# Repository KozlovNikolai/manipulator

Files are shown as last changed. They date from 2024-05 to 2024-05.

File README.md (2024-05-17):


<!-- PROJECT LOGO -->
<br />
<div align="center">
  <a href="https://github.com/github_username/repo_name">
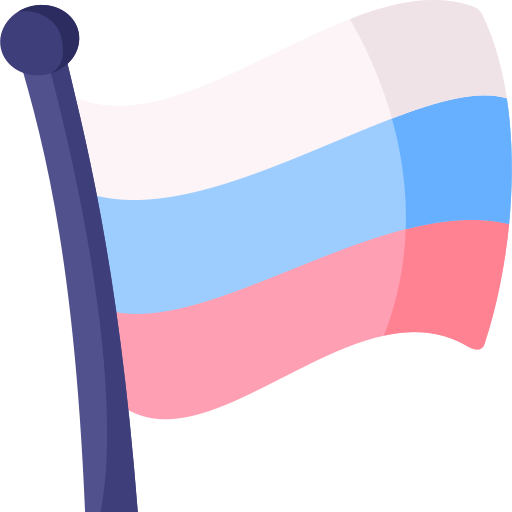
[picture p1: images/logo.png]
    
  </a>

<h3 align="center">Проект автоматического телеграфного ключа для тренировки и соревнований по скоростному телеграфированию</h3>

<!-- TABLE OF CONTENTS -->
<details>
  <summary>Содержание</summary>
  <ol>
    <li><a href="#о-проекте">О проекте</a></li>
    <li><a href="#начало">Начало</a></li>
    <li><a href="#лицензия">Лицензия</a></li>
    <li><a href="#контакты">Контакты</a></li>
  </ol>
</details>

<!-- ABOUT THE PROJECT -->
## О проекте

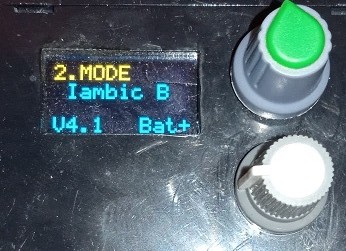
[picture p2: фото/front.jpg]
Product Name Screen Shot


<p align="left">
Проект был задуман как ответ на запрос от телеграфистов скоростников на изготовление автоматического ключа, отвещающего следующим требованиям:</p>

* <p align="left">скорость работы ключа не менее 400 СРМ</p>
* <p align="left">поддержка всех режимов работы манипулятора: Iambic A, Iambic AT, Iambic B, Classic</p>
* <p align="left">два выхода управления: реле и оптопара</p>
* <p align="left">звуковая индикация</p>
* <p align="left">индикация заряда батареи</p>
* <p align="left">режим тренировки/контест</p>
* <p align="left">вывод в текстовый редактор на компьютер набираемых символов (как будто их набирают на клавиатуре)</p>
* <p align="left">отображение всех настроек и режимов на дисплее</p>
* <p align="left">сохранение текущих настроек в энергонезависимую память</p>

Текущая версия = 4.32

<p align="right">(<a href="#readme-top">back to top</a>)</p>

<!-- GETTING STARTED -->
## Начало

Для установки программы требуются:

* Arduino IDE
* Микроконтроллер AtMega32u4

После прошивки требуется вставить контроллер в манипулятор, изготовленный в соответствии с <a href="https://github.com/KozlovNikolai/manipulator/tree/master/manipulyator">проектом</a>.

<p align="right">(<a href="#readme-top">back to top</a>)</p>

<!-- LICENSE -->
## Лицензия

Распостраняется свободно.

<p align="right">(<a href="#readme-top">back to top</a>)</p>

<!-- CONTACT -->
## Контакты

Николай Козлов:\
Telegram: @gremiha3\
e-mail: gremiha3@yandex.ru

Project Link: [https://github.com/KozlovNikolai/manipulator](https://github.com/KozlovNikolai/manipulator)

<p align="right">(<a href="#readme-top">back to top</a>)</p>

<!-- MARKDOWN LINKS & IMAGES -->
<!-- https://www.markdownguide.org/basic-syntax/#reference-style-links -->
[arduino-img]: https://cdn.arduino.cc/header-footer/prod/assets/headerLogo-arduino.svg
[arduino-link]: https://www.arduino.cc/
[front-img]: фото/front.jpg

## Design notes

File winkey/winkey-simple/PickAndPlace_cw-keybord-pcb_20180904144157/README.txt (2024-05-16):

为了支持多语言，立创EDA的BOM和坐标文件(CSV文件)均采用UNICODE编码，以制表符为CSV分隔符，如果你上传BOM至元件商城(如立创商城)无法使用，或者发送坐标文件至PCB制造商(如深圳嘉立创)无法使用，请自行转换CSV文件编码与分隔符。

推荐的转换方式：使用Excel或WPS另存为新的CSV文件。以Excel为例，用Excel打开CSV文件后，依次点击或选择：另存为——其它格式——CSV(逗号分隔)(*.csv)。

也可以使用任何文本编辑器(如Windows记事本)打开该CSV文件，另存为ANSI或UTF-8编码格式。如有必要，还需替换所有制表符为英文逗号。

In order to support multiple languages, BOM and coordinate files (CSV file) are UNICODE encoded and tab-based. If the CSV file cannot be read by your components vendor or PCB manufacturer, please convert the encoding and change the delimiter.

Recommended solution: Save as a new CSV file in Excel or WPS. For example, open a CSV file in Excel, click or select: Save As - Other Formats - CSV (Comma Separated) (*. csv).

You can also open the CSV file with any text editor (such as Windows Notepad) and save as ANSI or UTF-8 encoding. If necessary, replace all tabs with commas.

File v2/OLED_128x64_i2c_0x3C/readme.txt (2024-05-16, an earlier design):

Радиодетали недорого почтой из Москвы и в Москве круглосуточно 24/7, есть доставка - www.mkPochtoi.ru

миниатюрный дисплей около 24 мм диагональ 128х64 точки интерфес i2c 

1) в Arduino IDE открыть - скеч - Подкл библ - Добавить ZIP-библ
 и добавить  Adafruit_GFX.zip  а затем Adafruit_SSD1306.zip
 
2) подключите дисплей к Arduino через преобразователь уровей на 3.3 вольта (например через модуль согласования логических уровней)
 
3) в Arduino IDE открыть - Файл - открыть -  откройте скеч
C:\Users\......\Documents\Arduino\libraries\Adafruit_SSD1306\examples\ssd1306_128x64_i2c/ssd1306_128x64_i2c.ino

4) нажать кнопку "загрузить" - после компиляции и загрузки на дисплее должна появится демка

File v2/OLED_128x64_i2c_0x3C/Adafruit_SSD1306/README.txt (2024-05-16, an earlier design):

Радиодетали недорого почтой из Москвы и в Москве круглосуточно 24/7, есть доставка - www.mkPochtoi.ru

This is a library for our Monochrome OLEDs based on SSD1306 drivers

  Pick one up today in the adafruit shop!
  ------> http://www.adafruit.com/category/63_98

  i2c or
These displays use SPI to communicate, 4 or 5 pins are required to  
interface

Adafruit invests time and resources providing this open source code, 
please support Adafruit and open-source hardware by purchasing 
products from Adafruit!

Written by Limor Fried/Ladyada  for Adafruit Industries.  
Scrolling code contributed by Michael Gregg
BSD license, check license.txt for more information
All text above must be included in any redistribution

To download. click the DOWNLOADS button in the top right corner, rename the uncompressed folder Adafruit_SSD1306. Check that the Adafruit_SSD1306 folder contains Adafruit_SSD1306.cpp and Adafruit_SSD1306.h

Place the Adafruit_SSD1306 library folder your <arduinosketchfolder>/libraries/ folder. You may need to create the libraries subfolder if its your first library. Restart the IDE.

You will also have to download the Adafruit GFX Graphics core which does all the circles, text, rectangles, etc. You can get it from
https://github.com/adafruit/Adafruit-GFX-Library
and download/install that library as well

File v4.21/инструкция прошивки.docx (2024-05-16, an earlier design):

История изменений в самом конце!

1 Скачиваем «arduino ide» https://downloads.arduino.cc/arduino-1.8.13-windows.exe или зайти на сайт https://www.arduino.cc/en/software и выбрать нужную версию.
2 Устанавливаем, при установке оставляем все галки включая установку драйверов.

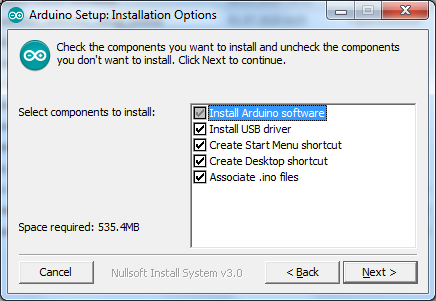
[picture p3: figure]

3 При установке доверяем программе во всех случаях:

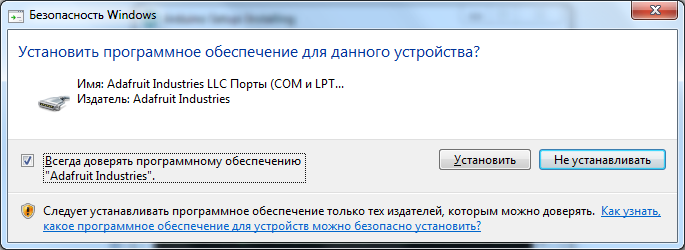
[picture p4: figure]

4 При появлении надписи «COMPLETED» нажимаем «CLOSE»

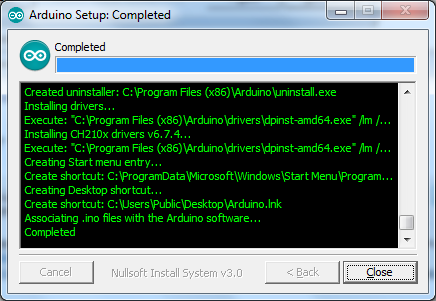
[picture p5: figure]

5 Запускаем Arduino IDE

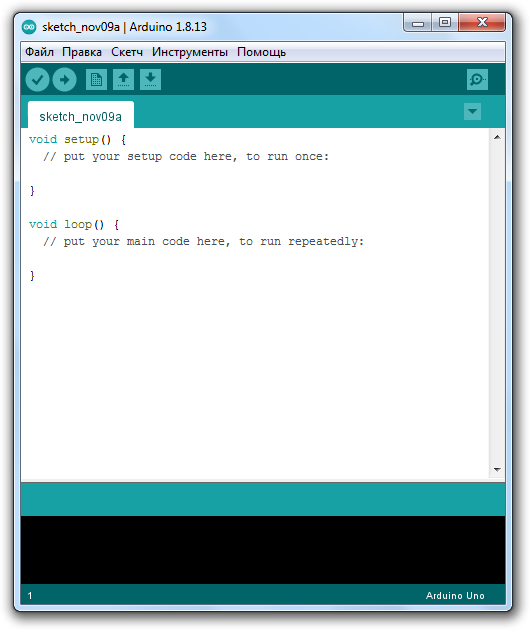
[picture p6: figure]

6 Открываем файл прошивки:

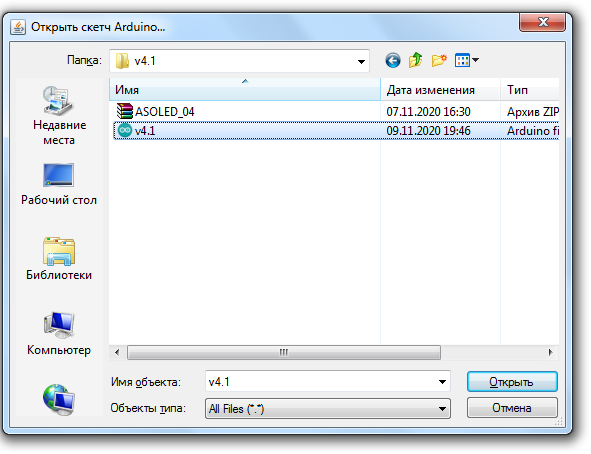
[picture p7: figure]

7 Выбираем нужный контроллер:

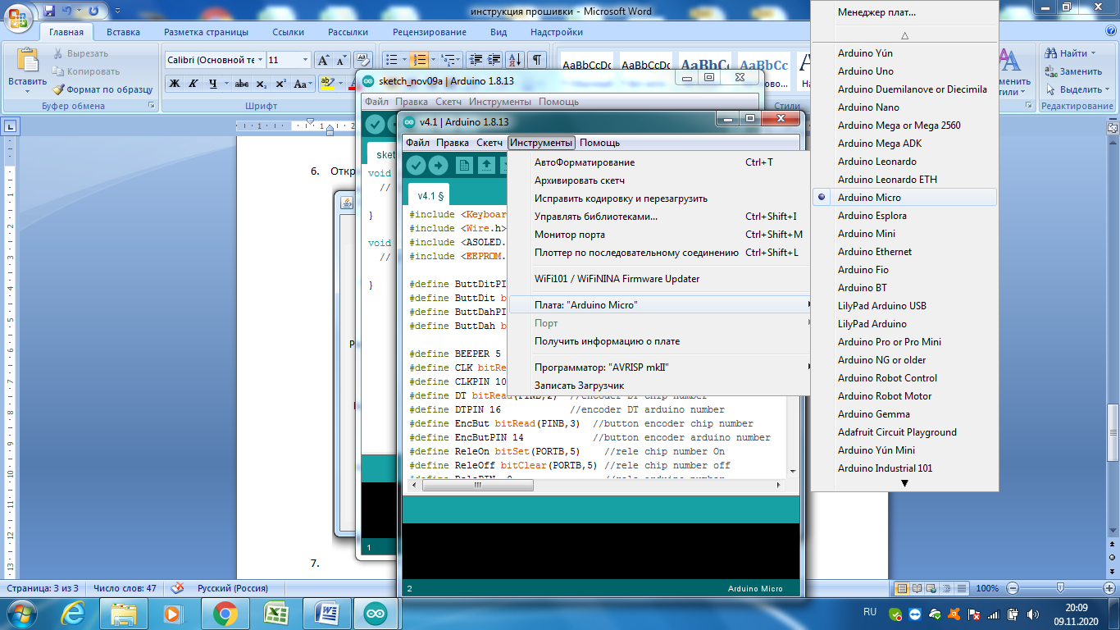
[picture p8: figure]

8 Подключаем контроллер в USB порт, если Arduino IDE установился правильно, то драйвер на контроллер установится автоматически:

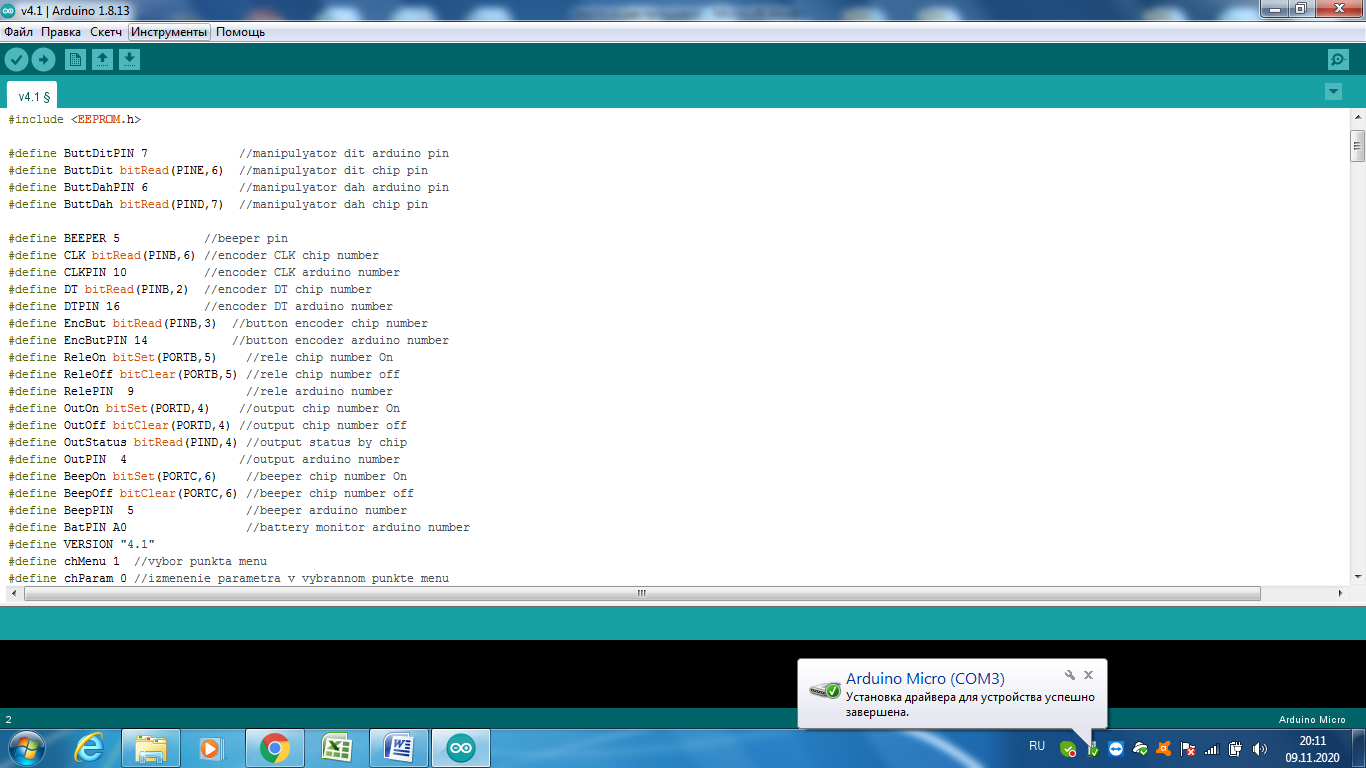
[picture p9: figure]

9 Выбираем порт:

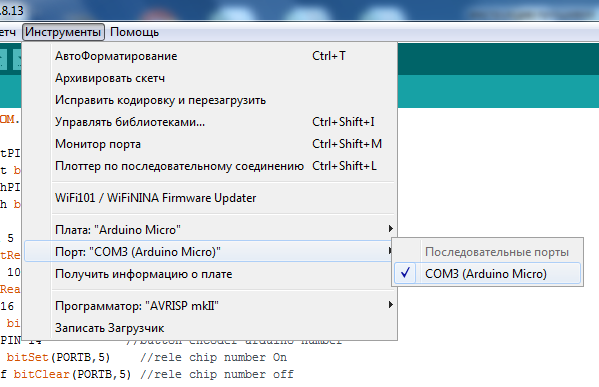
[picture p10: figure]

10 Добавляем недостающую библиотеку:

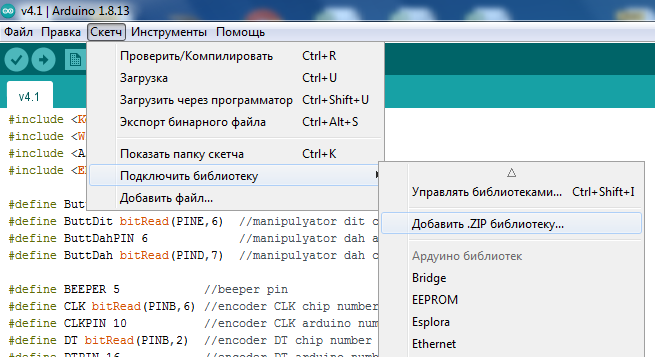
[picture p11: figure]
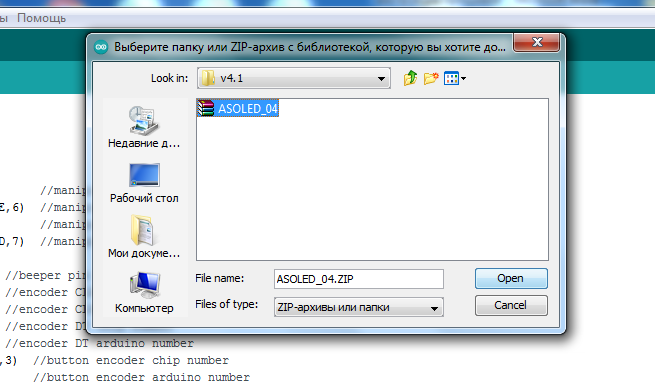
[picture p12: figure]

11 Нажимаем кнопку прошивки (указана стрелкой):

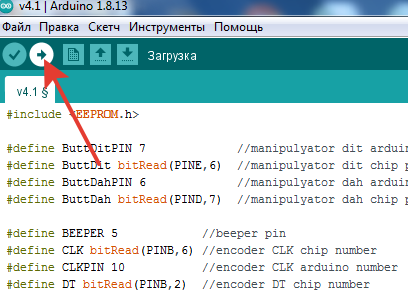
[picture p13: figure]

12 При прошивке может установиться дополнительный драйвер (обычно только при первой прошивке)

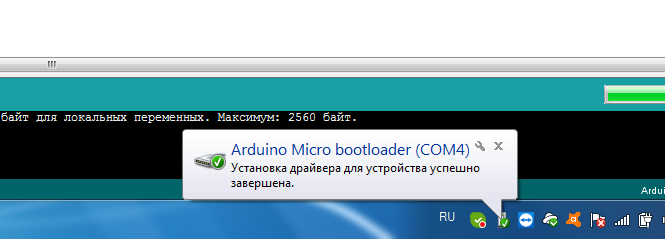
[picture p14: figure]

13 Если прошивка завершилась удачно, то появится надпись «Загрузка завершена»

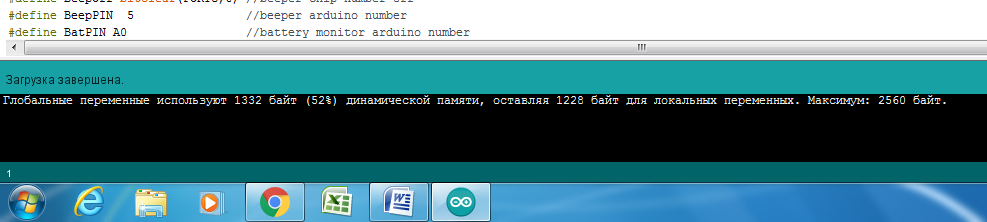
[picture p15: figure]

В нижнем правом углу есть индикатор батареи. Его значения:

- USB – питание от USB порта. При этом реле работать не будет (см. выше)
- Bat+ питание от батареи в норме.
- Bat- (мигает) напряжение упало до , примерно, 2.5 вольт.

Что бы функция батареи работала на устройствах с прошивкой V3.0, надо соединить контакт питания Реле с контактом А0 контроллера.

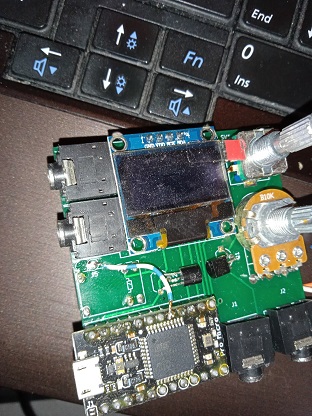
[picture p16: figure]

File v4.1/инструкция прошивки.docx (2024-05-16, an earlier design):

1 Скачиваем «arduino ide» https://downloads.arduino.cc/arduino-1.8.13-windows.exe или зайти на сайт https://www.arduino.cc/en/software и выбрать нужную версию.
2 Устанавливаем, при установке оставляем все галки включая установку драйверов.


3 При установке доверяем программе во всех случаях:


4 При появлении надписи «COMPLETED» нажимаем «CLOSE»


5 Запускаем Arduino IDE


6 Открываем файл прошивки:


7 Выбираем нужный контроллер:


8 Подключаем контроллер в USB порт, если Arduino IDE установился правильно, то драйвер на контроллер установится автоматически:


9 Выбираем порт:


10 Добавляем недостающую библиотеку:


11 Нажимаем кнопку прошивки (указана стрелкой):


12 При прошивке может установиться дополнительный драйвер (обычно только при первой прошивке)


13 Если прошивка завершилась удачно, то появится надпись «Загрузка завершена»


В прошивке 4.1 следующие функции:

1 Выбор скорости CPM, скорость WPM вычисляется как 1/5
2 Выбор режима работы (согласно диаграмм, приложенных ниже):
  2.a Ямбик А - чередование
  2.b Ямбик АТ – чередование + память на точку
  2.c Ямбик В – чередование + память на точку и тире
  2.d Классический – нет памяти и нет чередования
3 Функция клавиатуры. При включении питания всегда выключена.
4 Функция реле. Реле работает только при включенной батарее (питание по USB может быть тоже включено, но реле 3 вольтовое и его питание только от батареи. Можно заменить реле на 5 вольтовое, или через резистор запитать штатное реле, и запитать от 5 вольт после преобразователя – не пробовал, пока так)
5 Функция Автопаузы. Пока пустой пункт меню.
6 Длительность тире в размерности длительности точки.
7 Реверс что-бы поменять местами функции точки и тире на манипуляторе.
8 Долгое нажатие – сохраняет все настройки кроме Функции клавиатуры.

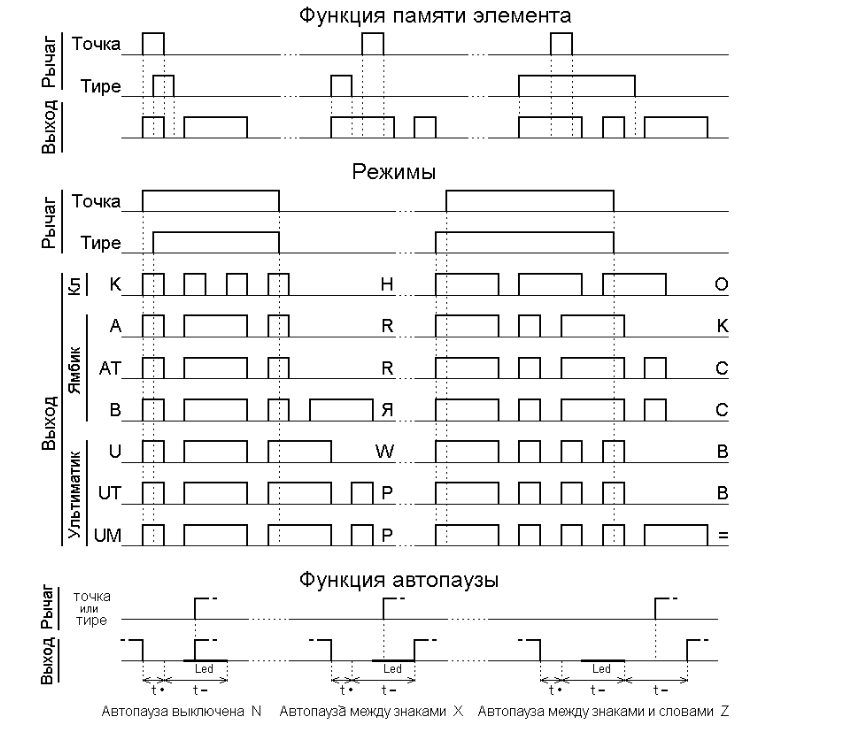
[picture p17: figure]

В нижнем правом углу есть индикатор батареи. Его значения:

- USB – питание от USB порта. При этом реле работать не будет (см. выше)
- Bat+ питание от батареи в норме.
- Bat- (мигает) напряжение упало до , примерно, 2.5 вольт.

Что бы функция батареи работала на устройствах с прошивкой V3.0, надо соединить контакт питания Реле с контактом А0 контроллера.


Остальные фото Меню:

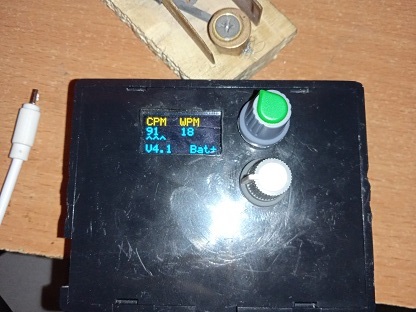
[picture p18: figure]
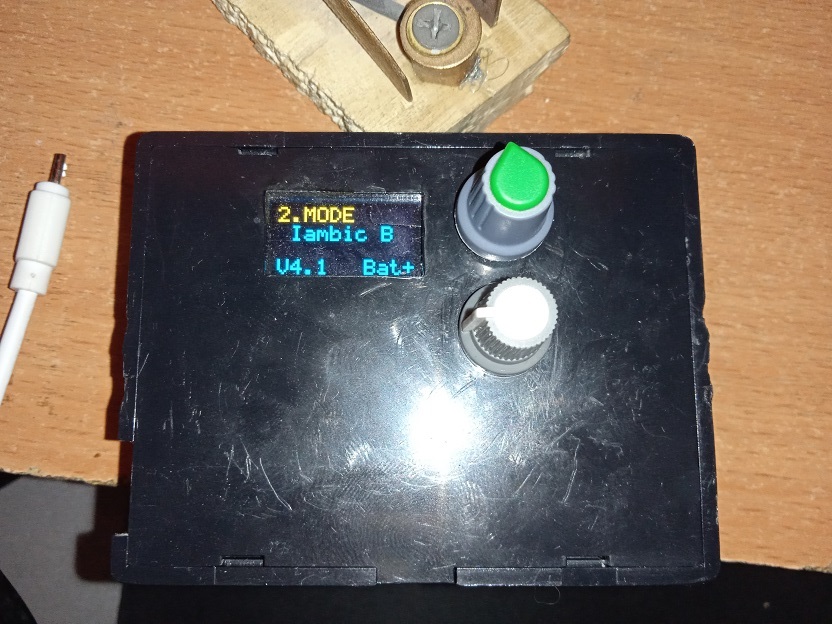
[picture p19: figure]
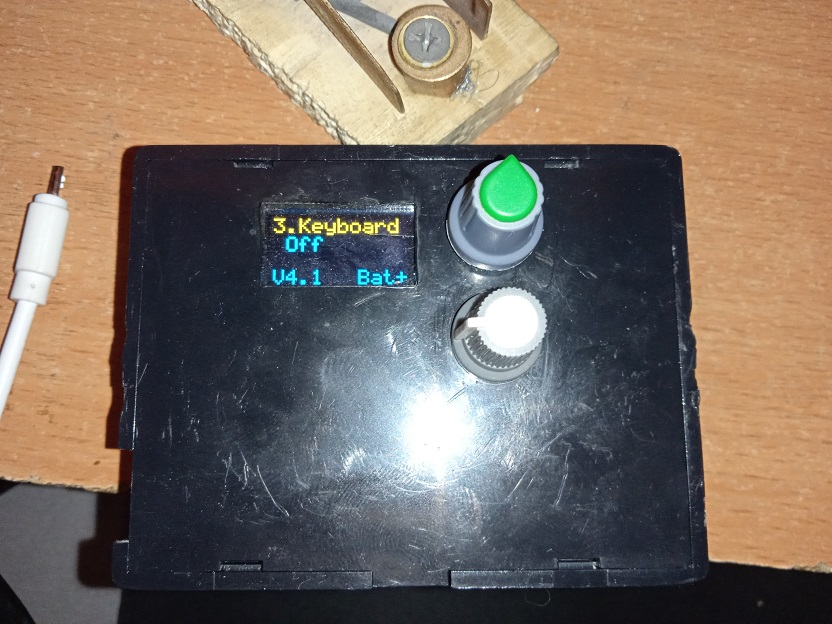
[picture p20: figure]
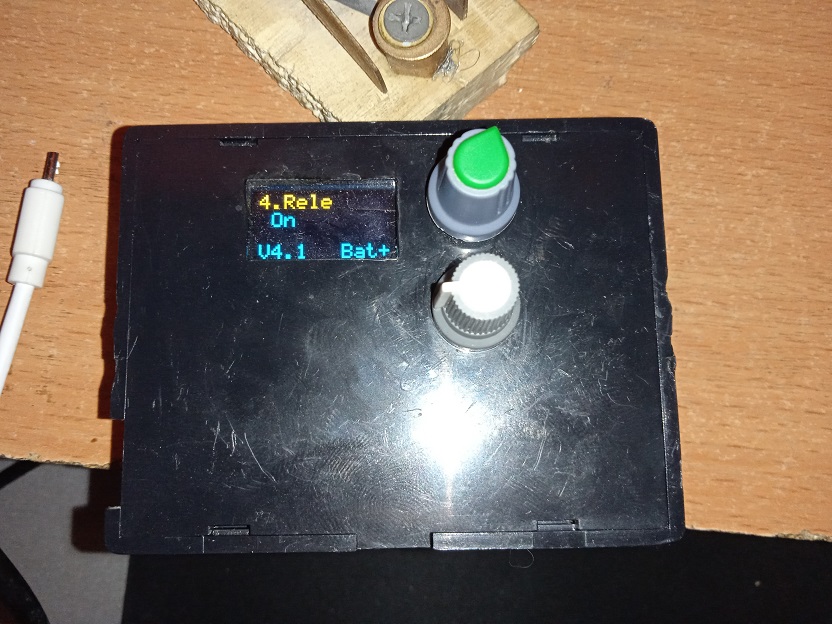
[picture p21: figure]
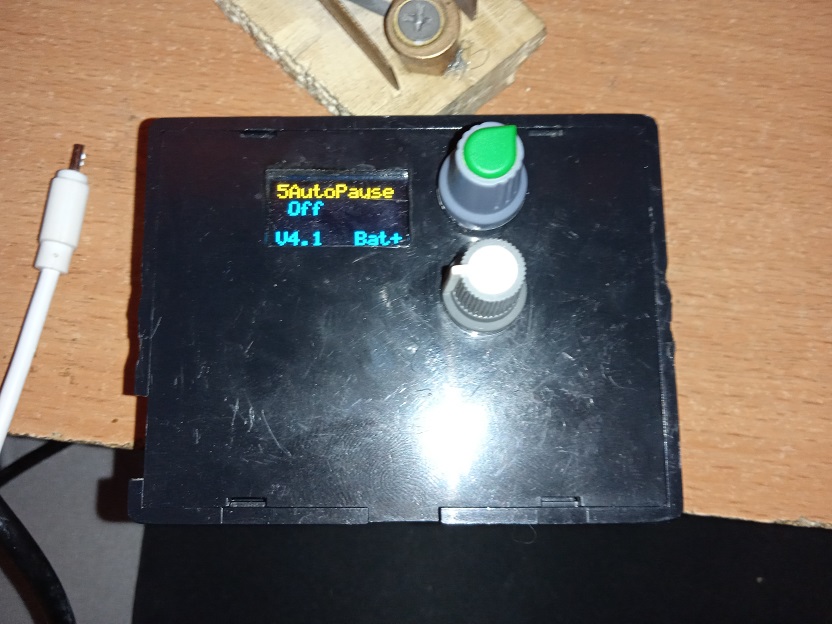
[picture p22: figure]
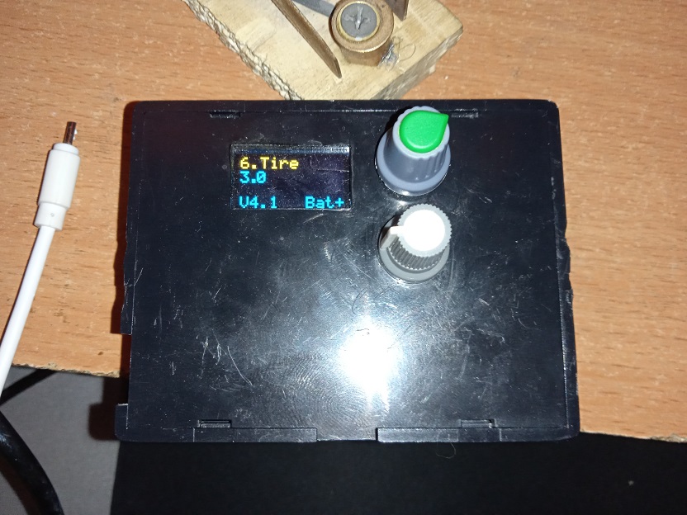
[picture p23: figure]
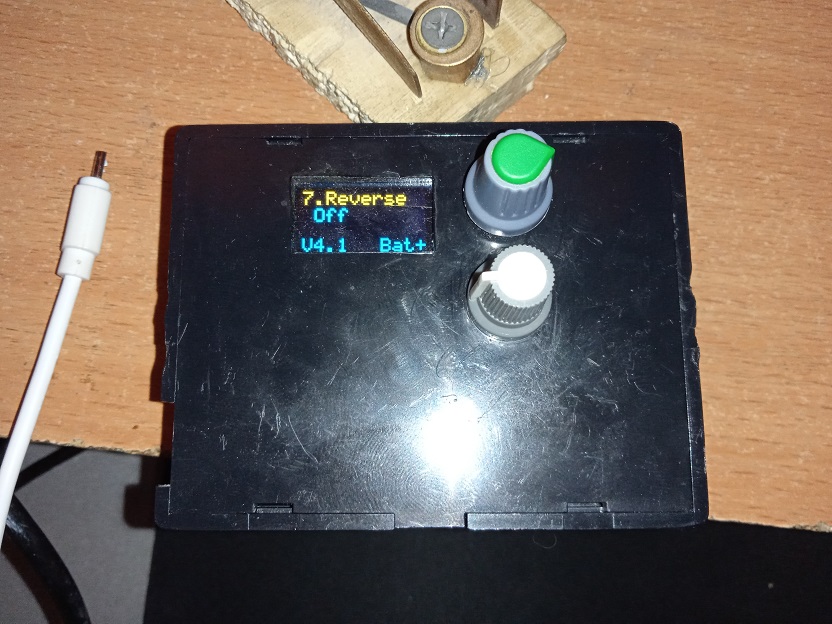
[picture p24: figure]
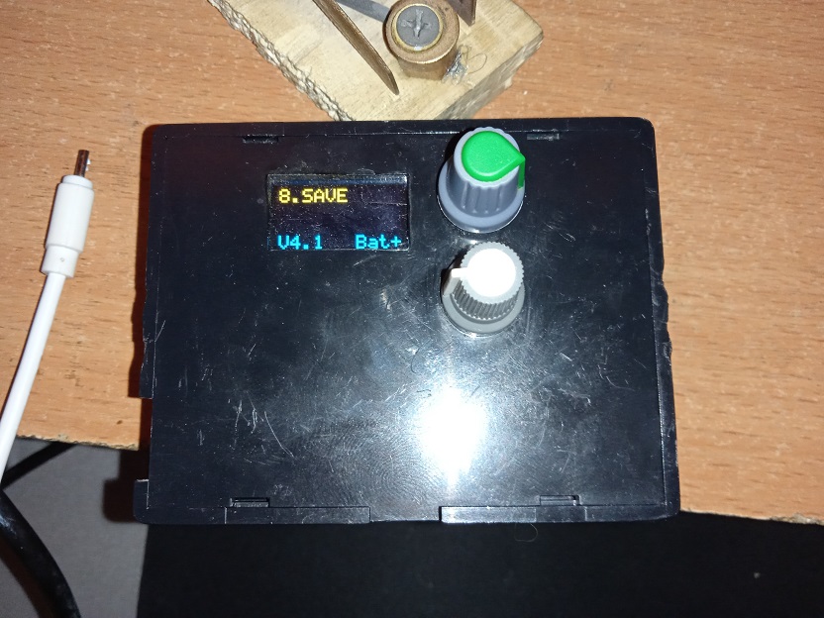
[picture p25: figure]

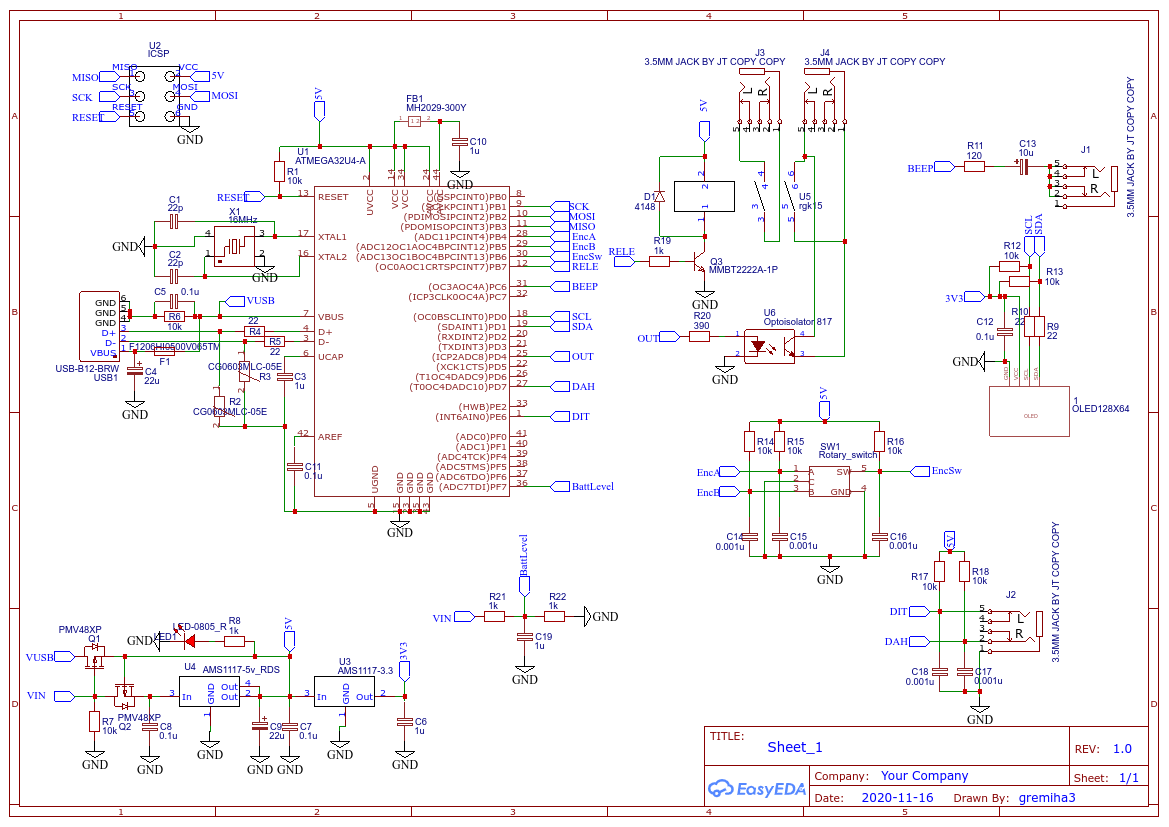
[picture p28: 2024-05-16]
v5/Schematic_manipulyator_2020-11-21_15-03-55.png

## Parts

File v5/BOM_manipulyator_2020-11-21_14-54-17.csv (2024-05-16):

ID | Name | Designator | Footprint | Quantity | Manufacturer Part | Manufacturer | Supplier | Supplier Part | LCSC Assembly
1 | OLED128X64 | 1 | OLED_128X64 | 1
2 | 4148 | D1 | D_0805 | 1
3 | rgk15 | U5 | RGK15.2 | 1
4 | LED-0805_R | LED1 | LED0805_RED | 1 | 17-21SURC/S530-A3/TR8 | EVERLIGHT(台湾亿光) |  | C72037
5 | AMS1117-3.3 | U3 | AMS_1117 | 1 | AMS1117-3.3 | AMS | LCSC | C6186 | Yes
6 | ATMEGA32U4-A | U1 | TQFP44 | 1
7 | Optoisolator 817 | U6 | PC817C SMD | 1 | FOD817A3SD | ON Semiconductor | Digi-Key | FOD817A3SDCT-ND
8 | ICSP | U2 | ICSP | 1
9 | 22u | C4,C9 | CASE-B_3528 | 2
10 | 10u | C13 | CASE-B_3528 | 1
11 | CG0603MLC-05E | R2,R3 | R0603 | 2 | CG0603MLC-05E
12 | 16MHz | X1 | OSC-SMD_4P-L3.2-W2.5-BL | 1 | 3225-16.00-12-10-10/A | Suzhou Liming Elec | LCSC | C518161
13 | AMS1117-5v_RDS | U4 | AMS_1117 | 1 | AMS1117-3.3 | AMS | LCSC | C6186
14 | MH2029-300Y | FB1 | BEADC2016X130N | 1
15 | MMBT2222A-1P | Q3 | SOT-23-3_L3.0-W1.7-P0.95-LS2.9-BR | 1 | MMBT2222A-1P | (MDD) Jiangsu Yutai Elec | LCSC | C364315 | Yes
16 | 22p | C1,C2 | C0805 | 2
17 | 1u | C3,C6,C10,C19 | C0805 | 4
18 | 0.1u | C5,C7,C8,C11,C12 | C0805 | 5
19 | 0.001u | C14,C15,C16,C17,C18 | C0805 | 5
20 | F1206HI0500V065TM | F1 | F1206 | 1 | F1206HI0500V065TM | AEM | LCSC | C310968
21 | USB-B12-BRW | USB1 | USB-B-TH_USB-B12-BRW | 1 | USB-B12-BRW | XUNPU | LCSC | C720550
22 | 3.5MM JACK BY JT COPY COPY | J1,J2,J3,J4 | STEREO 3.5MM JACK BY JT | 4 | PJ-324 3.5mmAudio sockets | jogjatechno.com | jogjatechno.com | jogjatechno.com
23 | 10k | R1,R6,R7,R12,R13,R14,R15,R16,R17,R18 | R0805 | 10
24 | 22 | R4,R5,R9,R10 | R0805 | 4
25 | 1k | R8,R19,R21,R22 | R0805 | 4
26 | 120 | R11 | R0805 | 1
27 | 390 | R20 | R0805 | 1
28 | Rotary_switch | SW1 | SW7-13.75X11.7X6.5MM | 1 | Rotary switch
29 | PMV48XP | Q1,Q2 | SOT-23-3_L2.9-W1.3-P1.90-LS2.4-BR | 2 | PMV48XP | VBsemi Elec | LCSC | C710049 | Yes

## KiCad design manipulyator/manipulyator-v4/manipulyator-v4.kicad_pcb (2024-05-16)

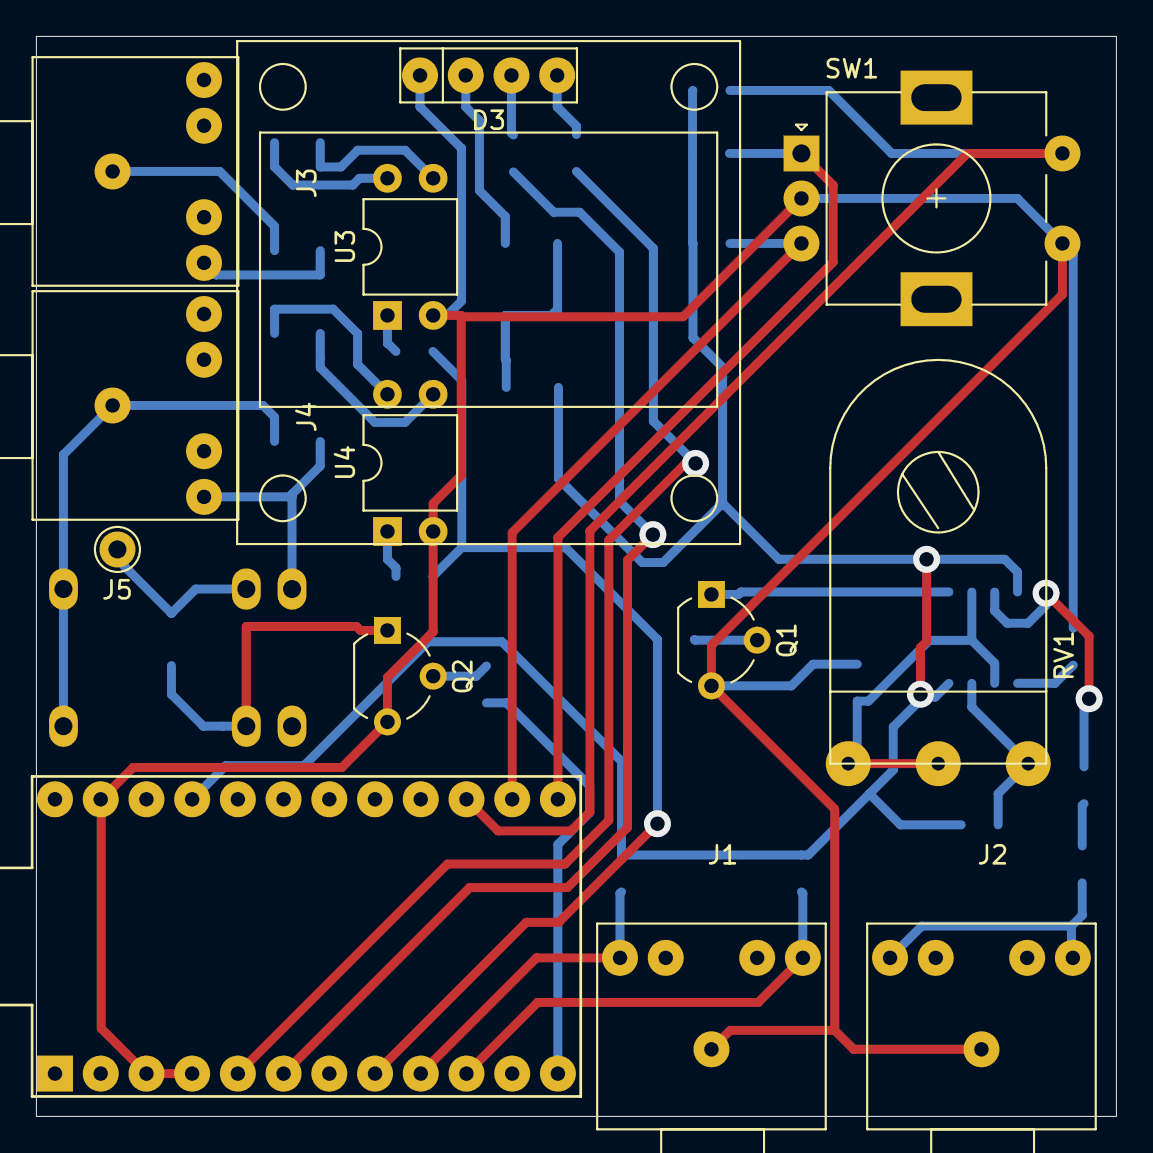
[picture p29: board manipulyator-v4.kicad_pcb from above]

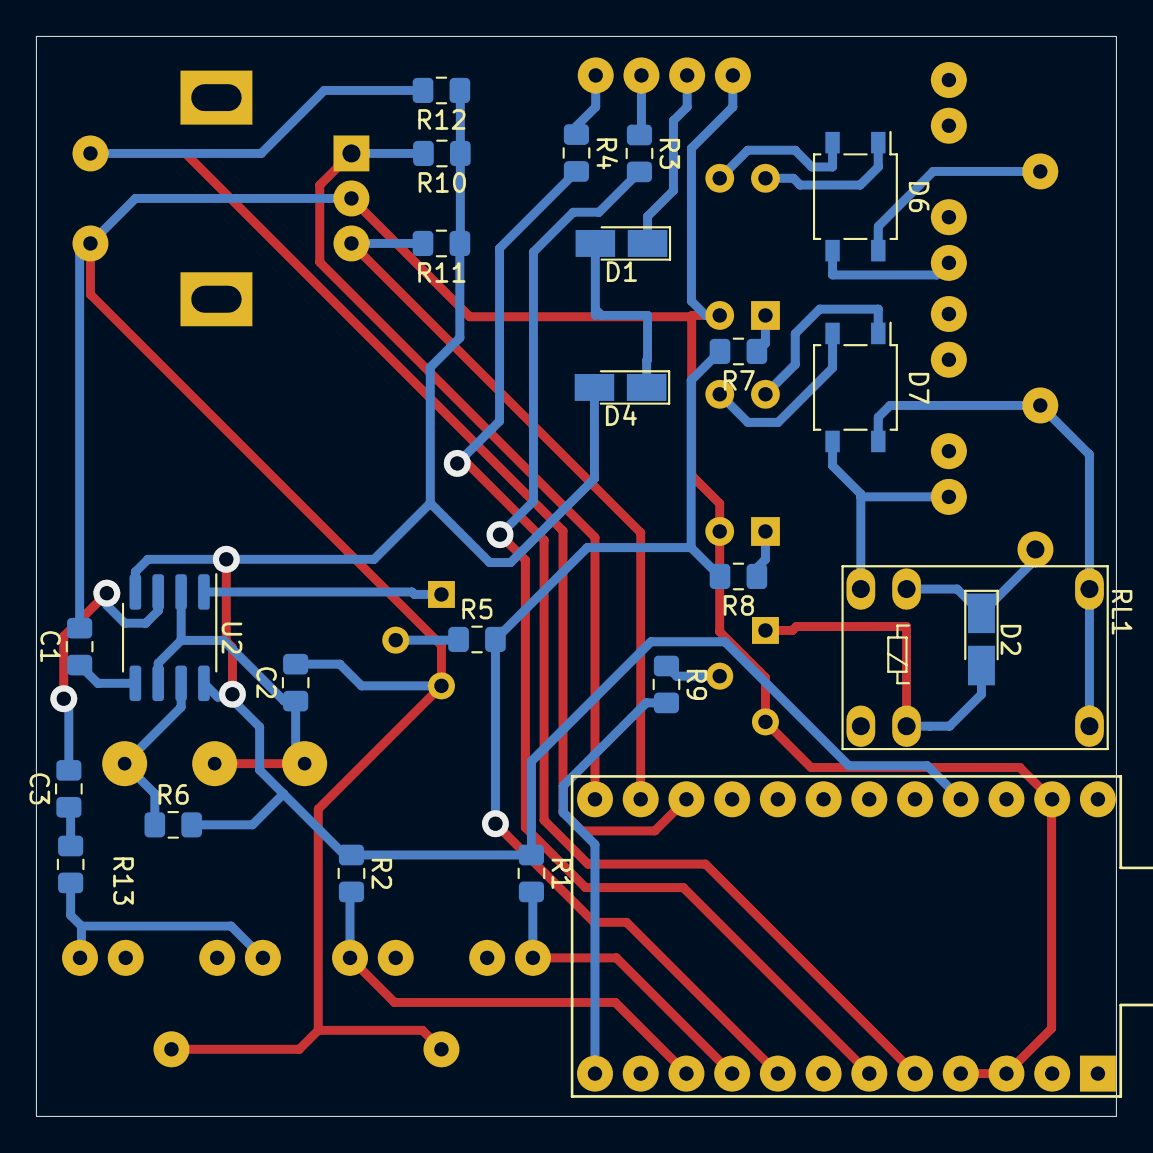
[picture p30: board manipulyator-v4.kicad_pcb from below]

Board: 2 copper layers, 60.0 x 60.0 mm, 36 parts (23 on the bottom side), 36 nets.

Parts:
C1: 0.01; C_0805_2012Metric_Pad1.15x1.40mm_HandSolder
C2, C3: 0.1; C_0805_2012Metric_Pad1.15x1.40mm_HandSolder
D1, D2, D4: 1N4148; D_MicroMELF_Hadsoldering
D3: oled_128x64_i2c_ssd1306
D6, D7: D_Bridge_+-AA; SO-4_4.4x4.3mm_P2.54mm
J1, J2, J3, J4: AudioJack2_Ground_Switch; audio-3.5mm-5pin
J5: Conn_01x01; Pin_D1.0mm_L10.0mm
Q1, Q2: BC547; TO-92_Wide
R1, R2, R5, R9: 4k7; R_0805_2012Metric_Pad1.15x1.40mm_HandSolder
R3, R4, R13: 100; R_0805_2012Metric_Pad1.15x1.40mm_HandSolder
R6, R10, R11, R12: 10k; R_0805_2012Metric_Pad1.15x1.40mm_HandSolder
R7, R8: 510; R_0805_2012Metric_Pad1.15x1.40mm_HandSolder
RL1: JRC-21F_4100; Relay_SPDT_HJR-4102
RV1: 10k; perem_resistor-step-5mm
SW1: Rotary_Encoder_Switch; RotaryEncoder_Alps_EC11E-Switch_Vertical_H20mm
U1: ProMicro
U2: NE555; SOP-8_3.76x4.96mm_P1.27mm
U3, U4: PC817; DIP-4_W7.62mm

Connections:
+5V: D4.2, R1.1, R2.1, R6.2, R10.1, R11.1, R12.1, U1.21, U2.4, U2.8
GND: C1.2, C2.2, D3.1, J1.G, J2.G, Q1.3, Q2.3, SW1.C, SW1.S1, U1.3, U1.4, U1.23, U3.2, U4.2
unnamed: C1.1, U2.5
unnamed: C2.1, RV1.1, RV1.2, U2.2, U2.6
unnamed: C3.1, R13.2
unnamed: C3.2, U2.3
unnamed: D1.1, D3.2
unnamed: D1.2, D4.1
unnamed: D2.1, J5.1, RL1.5
unnamed: D2.2, Q2.1, RL1.8
unnamed: D3.3, R3.1
unnamed: D3.4, R4.1
unnamed: D6.1, U3.4
unnamed: D6.2, U3.3
unnamed: D6.3, J3.T
unnamed: D6.4, J3.G
unnamed: D7.1, U4.4
unnamed: D7.2, U4.3
unnamed: D7.3, J4.T, RL1.6
unnamed: D7.4, J4.G, RL1.1, RL1.12
unnamed: J1.S, R1.2, U1.9
unnamed: J1.T, R2.2, U1.10
unnamed: J2.S, J2.T, R13.1
unnamed: Q1.1, U2.1
unnamed: Q1.2, R5.1
unnamed: Q2.2, R9.1
unnamed: R3.2, U1.6
unnamed: R4.2, U1.5
unnamed: R5.2, R7.2, R8.2, U1.8
unnamed: R6.1, RV1.3, U2.7
unnamed: R7.1, U3.1
unnamed: R8.1, U4.1
unnamed: R9.2, U1.12
unnamed: R10.2, SW1.A, U1.13
unnamed: R11.2, SW1.B, U1.14
unnamed: R12.2, SW1.S2, U1.15

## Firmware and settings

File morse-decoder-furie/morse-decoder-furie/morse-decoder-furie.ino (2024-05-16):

///////////////////////////////////////////////////////////////////////
// CW Decoder made by Hjalmar Skovholm Hansen OZ1JHM  VER 1.01       //
// Feel free to change, copy or what ever you like but respect       //
// that license is http://www.gnu.org/copyleft/gpl.html              //
// Discuss and give great ideas on                                   //
// https://groups.yahoo.com/neo/groups/oz1jhm/conversations/messages //
//                                                                   //
// Modifications by KC2UEZ. Bumped to VER 1.2:                       //
// Changed to work with the Arduino NANO.                            //
// Added selection of "Target Frequency" and "Bandwith" at power up. //
///////////////////////////////////////////////////////////////////////

///////////////////////////////////////////////////////////////////////////
// Read more here http://en.wikipedia.org/wiki/Goertzel_algorithm        //
// if you want to know about FFT the http://www.dspguide.com/pdfbook.htm //
///////////////////////////////////////////////////////////////////////////

#include <LiquidCrystal.h>

///////////////////////////////////////////////
// select the pins used on the LCD panel      /
///////////////////////////////////////////////
//  LiquidCrystal lcd(RS, E, D4, D5, D6, D7) //
///////////////////////////////////////////////

LiquidCrystal lcd(5,7,9,10,11,12); // Code changes to work with NANO by KC2UEZ

const int colums = 20; /// have to be 16 or 20
const int rows = 4;  /// have to be 2 or 4

int lcdindex = 0;
int line1[colums];
int line2[colums];

////////////////////////////////
// Define 8 specials letters  //
////////////////////////////////

byte U_umlaut[8] =   {B01010,B00000,B10001,B10001,B10001,B10001,B01110,B00000}; // 'Ü'  
byte O_umlaut[8] =   {B01010,B00000,B01110,B10001,B10001,B10001,B01110,B00000}; // 'Ö'  
byte A_umlaut[8] =   {B01010,B00000,B01110,B10001,B11111,B10001,B10001,B00000}; // 'Ä'    
byte AE_capital[8] = {B01111,B10100,B10100,B11110,B10100,B10100,B10111,B00000}; // 'Æ' 
byte OE_capital[8] = {B00001,B01110,B10011,B10101,B11001,B01110,B10000,B00000}; // 'Ø' 
byte fullblock[8] =  {B11111,B11111,B11111,B11111,B11111,B11111,B11111,B11111};  
byte AA_capital[8] = {B00100,B00000,B01110,B10001,B11111,B10001,B10001,B00000}; // 'Å'   
byte emtyblock[8] =  {B00000,B00000,B00000,B00000,B00000,B00000,B00000,B00000};  

int audioInPin = A7;  // Changed to work with Nano by KC2UEZ
int audioOutPin = 8;  // Changed to work with Nano by KC2UEZ
int ledPin = 13;

float magnitude ;
int magnitudelimit = 100;
int magnitudelimit_low = 100;
int realstate = LOW;
int realstatebefore = LOW;
int filteredstate = LOW;
int filteredstatebefore = LOW;


///////////////////////////////////////////////////////////
// The sampling frq will be 8928 on a 16 mhz             //
// without any prescaler etc                             //
// because we need the tone in the center of the bins    //
// you can set the tone to 496, 558, 744 or 992          //
// then n the number of samples which give the bandwidth //
// can be (8928 / tone) * 1 or 2 or 3 or 4 etc           //
// init is 8928/558 = 16 *4 = 64 samples                 //
// try to take n = 96 or 128 ;o)                         //
// 48 will give you a bandwidth around 186 hz            //
// 64 will give you a bandwidth around 140 hz            //
// 96 will give you a bandwidth around 94 hz             //
// 128 will give you a bandwidth around 70 hz            //
// BUT remember that high n take a lot of time           //
// so you have to find the compromice - i use 48         //
///////////////////////////////////////////////////////////

float coeff;
float Q1 = 0;
float Q2 = 0;
float sine;
float cosine;  
float sampling_freq=8928.0;
float target_freq=0.0; /// adjust for your needs see above
int n=0;  //// if you change  her please change next line also 
int testData[96];
float bw;

//////////////////////////////
// Noise Blanker time which //
// shall be computed so     //
// this is initial          //
//////////////////////////////
int nbtime = 6;  /// ms noise blanker         

long starttimehigh;
long highduration;
long lasthighduration;
long hightimesavg;
long lowtimesavg;
long startttimelow;
long lowduration;
long laststarttime = 0;

char code[20];
int stop = LOW;
int wpm;


////////////////
// init setup //
////////////////
void setup() {

////////////////////////////////////
// The basic goertzel calculation //
////////////////////////////////////

/////////////////////////////////////////////////////////////
// Modifications by KC2UEZ                                 //
// This code lets you select BW and Frequency at power up. //
/////////////////////////////////////////////////////////////

 pinMode(A0, INPUT_PULLUP);
 pinMode(A1, INPUT_PULLUP);
 pinMode(A2, INPUT_PULLUP);
 pinMode(A3, INPUT_PULLUP);

 if (!digitalRead(A0) && !digitalRead(A1))
   n=32;
 else if (!digitalRead(A0) && digitalRead(A1))
   n=48;
 else if (digitalRead(A0) && !digitalRead(A1))
   n=64;
 else
   n=96;

 if (!digitalRead(A2) && !digitalRead(A3))
   target_freq=496.0;
 else if (!digitalRead(A2) && digitalRead(A3))
   target_freq=558.0;
 else if (digitalRead(A2) && !digitalRead(A3))
   target_freq=744.0;
 else
   target_freq=992.0;

//////////////////////////
// End of modifications //
//////////////////////////

 bw = (sampling_freq/n);
 
  int  k;
  float omega;
  k = (int) (0.5 + ((n * target_freq) / sampling_freq));
  omega = (2.0 * PI * k) / n;
  sine = sin(omega);
  cosine = cos(omega);
  coeff = 2.0 * cosine;

///////////////////////////////
// define special characters //
///////////////////////////////
 lcd.createChar(0, U_umlaut); //     German
 lcd.createChar(1, O_umlaut); //     German, Swedish
 lcd.createChar(2, A_umlaut); //     German, Swedish 
 lcd.createChar(3, AE_capital); //   Danish, Norwegian
 lcd.createChar(4, OE_capital); //   Danish, Norwegian
 lcd.createChar(5, fullblock);        
 lcd.createChar(6, AA_capital); //   Danish, Norwegian, Swedish
 lcd.createChar(7, emtyblock); 
 lcd.clear(); 

 Serial.begin(115200); 
 pinMode(ledPin, OUTPUT);
 
 lcd.begin(colums, rows); 
 for (int index = 0; index < colums; index++){
    line1[index] = 32;
  line2[index] = 32;
 }           

}

///////////////
// main loop //
///////////////
 void loop() {

  ///////////////////////////////////// 
  // The basic where we get the tone //
  /////////////////////////////////////
  
  for (char index = 0; index < n; index++)
  {
    testData[index] = analogRead(audioInPin);
  }
  for (char index = 0; index < n; index++){
    float Q0;
    Q0 = coeff * Q1 - Q2 + (float) testData[index];
    Q2 = Q1;
    Q1 = Q0;  
  }
  float magnitudeSquared = (Q1*Q1)+(Q2*Q2)-Q1*Q2*coeff;  // we do only need the real part //
  magnitude = sqrt(magnitudeSquared);
  Q2 = 0;
  Q1 = 0;

  //Serial.print(magnitude); Serial.println();  //// here you can measure magnitude for setup..
  
  /////////////////////////////////////////////////////////// 
  // here we will try to set the magnitude limit automatic //
  ///////////////////////////////////////////////////////////
  
  if (magnitude > magnitudelimit_low){
    magnitudelimit = (magnitudelimit +((magnitude - magnitudelimit)/6));  /// moving average filter
  }
 
  if (magnitudelimit < magnitudelimit_low)
  magnitudelimit = magnitudelimit_low;
  
  ////////////////////////////////////
  // now we check for the magnitude //
  ////////////////////////////////////

  if(magnitude > magnitudelimit*0.6) // just to have some space up 
     realstate = HIGH; 
  else
    realstate = LOW; 
  
  ///////////////////////////////////////////////////// 
  // here we clean up the state with a noise blanker //
  /////////////////////////////////////////////////////
 
  if (realstate != realstatebefore){
  laststarttime = millis();
  }
  if ((millis()-laststarttime)> nbtime){
  if (realstate != filteredstate){
    filteredstate = realstate;
  }
  }
 
 ////////////////////////////////////////////////////////////
 // Then we do want to have some durations on high and low //
 ////////////////////////////////////////////////////////////
 
 if (filteredstate != filteredstatebefore){
  if (filteredstate == HIGH){
    starttimehigh = millis();
    lowduration = (millis() - startttimelow);
  }

  if (filteredstate == LOW){
    startttimelow = millis();
    highduration = (millis() - starttimehigh);
        if (highduration < (2*hightimesavg) || hightimesavg == 0){
      hightimesavg = (highduration+hightimesavg+hightimesavg)/3;     // now we know avg dit time ( rolling 3 avg)
    }
    if (highduration > (5*hightimesavg) ){
      hightimesavg = highduration+hightimesavg;     // if speed decrease fast ..
    }
  }
  }

 ///////////////////////////////////////////////////////////////
 // now we will check which kind of baud we have - dit or dah //
 // and what kind of pause we do have 1 - 3 or 7 pause        //
 // we think that hightimeavg = 1 bit                         //
 ///////////////////////////////////////////////////////////////
 
 if (filteredstate != filteredstatebefore){
  stop = LOW;
  if (filteredstate == LOW){  //// we did end a HIGH
   if (highduration < (hightimesavg*2) && highduration > (hightimesavg*0.6)){ /// 0.6 filter out false dits
  strcat(code,".");
  Serial.print(".");
   }
   if (highduration > (hightimesavg*2) && highduration < (hightimesavg*6)){ 
  strcat(code,"-");
  Serial.print("-");
  wpm = (wpm + (1200/((highduration)/3)))/2;  //// the most precise we can do ;o)
   }
  }
 
   if (filteredstate == HIGH){  //// we did end a LOW
   
   float lacktime = 1;
   if(wpm > 25)lacktime=1.0; ///  when high speeds we have to have a little more pause before new letter or new word 
   if(wpm > 30)lacktime=1.2;
   if(wpm > 35)lacktime=1.5;
   
   if (lowduration > (hightimesavg*(2*lacktime)) && lowduration < hightimesavg*(5*lacktime)){ // letter space
    docode();
  code[0] = '\0';
  Serial.print("/");
   }
   if (lowduration >= hightimesavg*(5*lacktime)){ // word space
    docode();
  code[0] = '\0';
  printascii(32);
  Serial.println();
   }
  }
 }
 
 //////////////////////////////
 // write if no more letters //
 //////////////////////////////

  if ((millis() - startttimelow) > (highduration * 6) && stop == LOW){
   docode();
   code[0] = '\0';
   stop = HIGH;
  }

 /////////////////////////////////////
 // we will turn on and off the LED //
 // and the speaker                 //
 /////////////////////////////////////
 
   if(filteredstate == HIGH){ 
     digitalWrite(ledPin, HIGH);
   tone(audioOutPin,target_freq);
   }
   else{
     digitalWrite(ledPin, LOW);
   noTone(audioOutPin);
   }
 
 //////////////////////////////////
 // the end of main loop clean up//
 /////////////////////////////////
 updateinfolinelcd();
 realstatebefore = realstate;
 lasthighduration = highduration;
 filteredstatebefore = filteredstate;
 }


////////////////////////////////
// translate cw code to ascii //
////////////////////////////////

void docode(){
    if (strcmp(code,".-") == 0) printascii(65);
  if (strcmp(code,"-...") == 0) printascii(66);
  if (strcmp(code,"-.-.") == 0) printascii(67);
  if (strcmp(code,"-..") == 0) printascii(68);
  if (strcmp(code,".") == 0) printascii(69);
  if (strcmp(code,"..-.") == 0) printascii(70);
  if (strcmp(code,"--.") == 0) printascii(71);
  if (strcmp(code,"....") == 0) printascii(72);
  if (strcmp(code,"..") == 0) printascii(73);
  if (strcmp(code,".---") == 0) printascii(74);
  if (strcmp(code,"-.-") == 0) printascii(75);
  if (strcmp(code,".-..") == 0) printascii(76);
  if (strcmp(code,"--") == 0) printascii(77);
  if (strcmp(code,"-.") == 0) printascii(78);
  if (strcmp(code,"---") == 0) printascii(79);
  if (strcmp(code,".--.") == 0) printascii(80);
  if (strcmp(code,"--.-") == 0) printascii(81);
  if (strcmp(code,".-.") == 0) printascii(82);
  if (strcmp(code,"...") == 0) printascii(83);
  if (strcmp(code,"-") == 0) printascii(84);
  if (strcmp(code,"..-") == 0) printascii(85);
  if (strcmp(code,"...-") == 0) printascii(86);
  if (strcmp(code,".--") == 0) printascii(87);
  if (strcmp(code,"-..-") == 0) printascii(88);
  if (strcmp(code,"-.--") == 0) printascii(89);
  if (strcmp(code,"--..") == 0) printascii(90);

  if (strcmp(code,".----") == 0) printascii(49);
  if (strcmp(code,"..---") == 0) printascii(50);
  if (strcmp(code,"...--") == 0) printascii(51);
  if (strcmp(code,"....-") == 0) printascii(52);
  if (strcmp(code,".....") == 0) printascii(53);
  if (strcmp(code,"-....") == 0) printascii(54);
  if (strcmp(code,"--...") == 0) printascii(55);
  if (strcmp(code,"---..") == 0) printascii(56);
  if (strcmp(code,"----.") == 0) printascii(57);
  if (strcmp(code,"-----") == 0) printascii(48);

  if (strcmp(code,"..--..") == 0) printascii(63);
  if (strcmp(code,".-.-.-") == 0) printascii(46);
  if (strcmp(code,"--..--") == 0) printascii(44);
  if (strcmp(code,"-.-.--") == 0) printascii(33);
  if (strcmp(code,".--.-.") == 0) printascii(64);
  if (strcmp(code,"---...") == 0) printascii(58);
  if (strcmp(code,"-....-") == 0) printascii(45);
  if (strcmp(code,"-..-.") == 0) printascii(47);

  if (strcmp(code,"-.--.") == 0) printascii(40);
  if (strcmp(code,"-.--.-") == 0) printascii(41);
  if (strcmp(code,".-...") == 0) printascii(95);
  if (strcmp(code,"...-..-") == 0) printascii(36);
  if (strcmp(code,"...-.-") == 0) printascii(62);
  if (strcmp(code,".-.-.") == 0) printascii(60);
  if (strcmp(code,"...-.") == 0) printascii(126);
  //////////////////
  // The specials //
  //////////////////
  if (strcmp(code,".-.-") == 0) printascii(3);
  if (strcmp(code,"---.") == 0) printascii(4);
  if (strcmp(code,".--.-") == 0) printascii(6);

}

/////////////////////////////////////
// print the ascii code to the lcd //
// one a time so we can generate   //
// special letters                 //
/////////////////////////////////////
void printascii(int asciinumber){

int fail = 0;
if (rows == 4 and colums == 16)fail = -4; /// to fix the library problem with 4*16 display http://forum.arduino.cc/index.php/topic,14604.0.html
 
 if (lcdindex > colums-1){
  lcdindex = 0;
  if (rows==4){
    for (int i = 0; i <= colums-1 ; i++){
    lcd.setCursor(i,rows-3);
    lcd.write(line2[i]);
    line2[i]=line1[i];
    }
   }
  for (int i = 0; i <= colums-1 ; i++){
    lcd.setCursor(i+fail,rows-2);
    lcd.write(line1[i]);
  lcd.setCursor(i+fail,rows-1);
    lcd.write(32);
  }
 }
 line1[lcdindex]=asciinumber;
 lcd.setCursor(lcdindex+fail,rows-1);
 lcd.write(asciinumber);
 lcdindex += 1;
}

void updateinfolinelcd(){
/////////////////////////////////////
// here we update the upper line   //
// with the speed.                 //
/////////////////////////////////////

// Modify to work with Frequency and BW selection. By KC2UEZ
  int place;
  if (rows == 4){
   place = 0;}
  else{
   place = 2;
  }
     
        lcd.setCursor(0,0);
        if (wpm < 10)
            lcd.print("0");
        else 
           lcd.setCursor(0,0);                   
    lcd.print(wpm);
        lcd.setCursor(2,0);
    lcd.print(" WPM ");
        lcd.setCursor(7,0);
    lcd.print((int)target_freq);
        lcd.setCursor(10,0);
    lcd.print(" TF ");
        lcd.setCursor(14,0);
        if (bw < 100)
           lcd.print(" "); 
    lcd.print((int)bw);
    lcd.print(" BW");
}

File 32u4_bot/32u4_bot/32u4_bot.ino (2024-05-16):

#include <Keyboard.h>
//================================================================================================================
// Настройки кнопок.
//================================================================================================================

// Кнопка-точка будет слева.
#define BUTTON_DOT   6
// Кнопка-тире - справа.
#define BUTTON_TIRE  7

int buttons, buttonsPrev; // Здесь будем в виде битовых масок хранить нынешнее и предыдущее состояние клавиш.
#define BUTTON_DOT_MASK   1
#define BUTTON_TIRE_MASK  2

// С помощью этих переменных мы засекаем, когда в последний раз была нажата и отпущена кнопка. Любая. По этому
//  времени мы определяем, завершен ли ввод текущего символа и не пора ли переходить в спящий режим.
unsigned long int timeRelease, timePress;

// Смену состояния кнопки на время менее 0.03с будем считать дребезгом и игнорировать.
#define DEBOUNCING_TIME  30
// В эти переменные будем сохранять время для отфильтровывания дребезга контактов.
unsigned long int timeDotDebouncing;
unsigned long int timeTireDebouncing;

// Максимальная пауза между точками и тире в букве - 0.4 секунды.
//  Если пауза больше - считаем ввод буквы завершенным и переходим к вводу следующей буквы.
#define DELIMITER_TIME  500

//================================================================================================================
// Настройки пьезо-динамика.
//================================================================================================================

#define PIEZO  8
byte piezoData;
unsigned long int piezoShutUpTime;

//================================================================================================================
// Азбука Морзе.
//================================================================================================================

// Этими символами мы будем обозначать точки и тире.
#define MORSE_DOT     '*'
#define MORSE_TIRE    '-'
// Точка или тире пока не введены. 
#define MORSE_EMPTY   0
// Это - для блокировки ввода точек/тире при смене раскладки или выходе из спящего режима.
#define MORSE_LOCKED  '!'

// Максимальная длина символа азбуки Морзе (в точках и тире)
#define MAX_MORSE_SYMBOL_LENGTH  8
// Буфер для записи морзе-символа.
byte morseSymbol[MAX_MORSE_SYMBOL_LENGTH];
unsigned int morseSymbolLen;
byte newMorseSignal; // Новый введенный сигнал - точка или тире.

// Таблица кодов Морзе. N-ный элемент кода соответствует n-ному символу раскладки.
char* code[] = {
  "*-","-***","*--","--*","-**","*","***-","--**","**","*---",
  "-*-","*-**","--","-*","---","*--*","*-*","***","-","**-",
  "**-*","****","-*-*","---*","----","--*-","-*--","-**-","**-**","**--",
  "*-*-",
  "*----","**---","***--","****-","*****","-****","--***","---**","----*","-----",
  "......","*-*-*-","---***","-*-*-","-*--*-","*----*","*-**-*","-****-","-**-*","**--**","--**--",
  "-***-","********","*--*-*","**-*-",
  ""
};

// Латинская раскладка.
char* layoutLatin[] = {
  "a","b","w","g","d","e","v","z","i","j",
  "k","l","m","n","o","p","r","s","t","u",
  "f","h","c","ö","ch","q","y","x","é","ü",
  "ä",
  "1","2","3","4","5","6","7","8","9","0",
  ".",",",":",";","(","\'","\"","-","/","?","!",
  " *DELIMITER* "," *ERR* ","@"," *END* ",
  ""
};

char** currentLayout;
char** newLayout;

//================================================================================================================
// Режимы работы.
//================================================================================================================

#define TYPING_MODE  0
int mode;

//================================================================================================================

void setup() {
   Keyboard.begin();
  Serial.begin(9600);
  // И кнопки, и светодиод у нас работают с инвертированной логикой: кнопка нажата = LOW, отпущена = HIGH,
  //  светодиод горит на полную яркость = LOW, погашен = HIGH. Погасим светодиоды:

  pinMode(PIEZO, OUTPUT);
  digitalWrite(PIEZO, LOW);

  pinMode(BUTTON_DOT, INPUT);
  pinMode(BUTTON_TIRE, INPUT);
  buttons = 0;
  buttonsPrev = 0;
  
  mode = TYPING_MODE;

  morseSymbolLen = 0;

  currentLayout = layoutLatin;
  newLayout = 0;
  newMorseSignal = MORSE_EMPTY;
}

//================================================================================================================
// Работа с пьезо-динамиком
void doPiezo(unsigned long int currentTime) {
  if (currentTime >= piezoShutUpTime) {
    if (piezoShutUpTime > 0) {
      piezoShutUpTime = 0;
      digitalWrite(PIEZO, LOW);
    }
    return;
  }
  piezoData = (piezoData == LOW) ? HIGH : LOW;
  digitalWrite(PIEZO, piezoData);
}

void playPiezo(unsigned long int t, unsigned long int currentTime) {
  piezoShutUpTime = currentTime + t;
}

//================================================================================================================
// Считывание состояния кнопки с учетом возможного дребезга контактов.
int getButtonState(int btnPrevState, int BUTTON_PIN, unsigned long int* timeDebouncing, unsigned long int currentTime) {
  int btnState = digitalRead(BUTTON_PIN);
  
  if (btnState == HIGH) {
    if (btnPrevState == LOW) {
      if (*timeDebouncing == 0) {
        // Засечем время, которое кнопка будет нажата - чтобы не спутать дребезг контактов с нажатием.
        *timeDebouncing = currentTime;
        // Пока не воспринимаем нажатие, считая его дребезгом контактов.
        btnState = LOW;
      } else {
        if ((currentTime - *timeDebouncing) < DEBOUNCING_TIME) {
          // Пока не воспринимаем нажатие, считая его дребезгом контактов.
          btnState = LOW;
        } else {
          // Это не дребезг контактов, это реальное нажатие кнопки.
          btnState = HIGH;
          *timeDebouncing = 0;
        }
      }
    } else {
      *timeDebouncing = 0;
    }
  } else {
    if (btnPrevState == HIGH) {
      if (*timeDebouncing == 0) {
        // Засечем время, которое кнопка будет нажата - чтобы не спутать дребезг контактов с нажатием.
        *timeDebouncing = currentTime;
        // Пока не воспринимаем отпускание, считая его дребезгом контактов.
        btnState = HIGH;
      } else {
        if ((currentTime - *timeDebouncing) < DEBOUNCING_TIME) {
          // Пока не воспринимаем отпускание, считая его дребезгом контактов.
          btnState = HIGH;
        } else {
          // Это не дребезг контактов, это реальное отпукание кнопки.
          btnState = LOW;
          *timeDebouncing = 0;
        }
      }
    } else {
      *timeDebouncing = 0;
    }
  }
  
  return btnState;
}
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

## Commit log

2024-05-16 push to git
    [BOM_manipulyator_2020-11-21_14-54-17.csv, BOM_manipulyator_2020-11-21_14-54-17.ods, PickAndPlace_cw-keybord-pcb_20180904144157.csv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]
2024-05-16 add pcb
    [manipulyator-v3 (2)-B_Cu.gbl, manipulyator-v3 (2)-B_Cu.gbr, manipulyator-v3 (2)-B_Mask.gbr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]
